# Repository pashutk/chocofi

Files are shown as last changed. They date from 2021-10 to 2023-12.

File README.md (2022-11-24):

# chocofi

Keyboard shield and 3d printed case to use with Arduino ProMicro-like contoller.

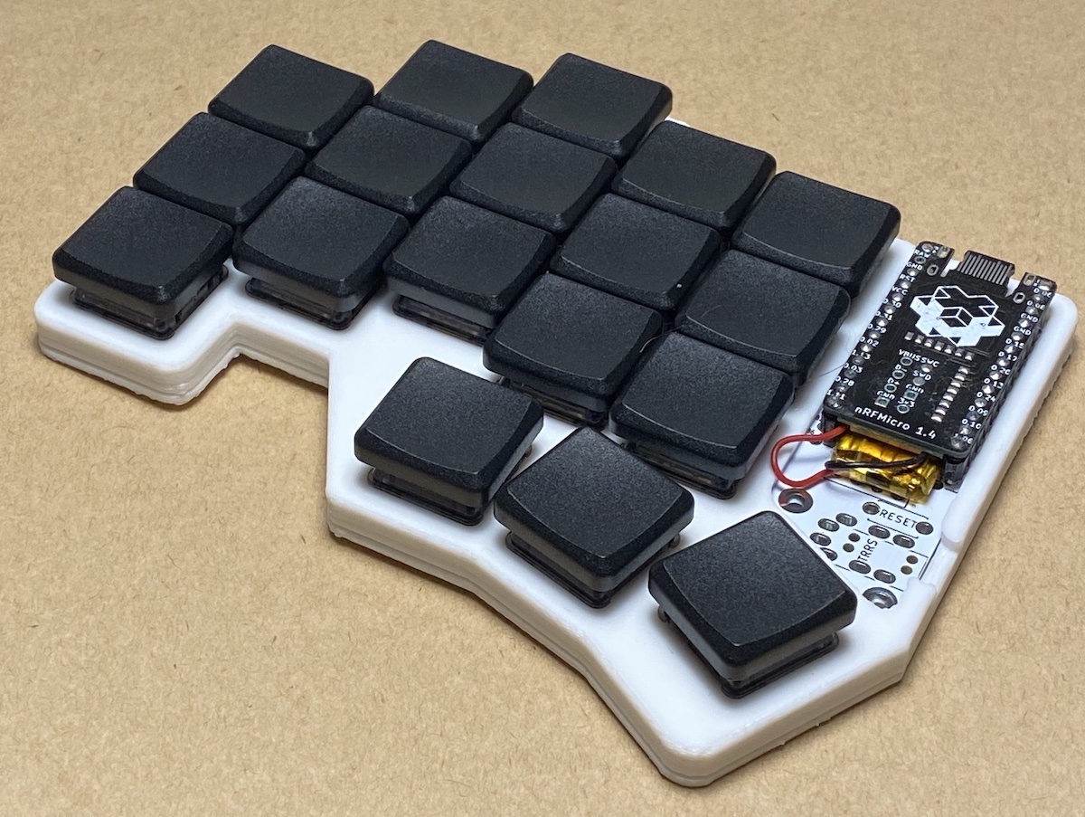
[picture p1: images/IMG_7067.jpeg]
Photo of a chocofi keyboard


- Split keyboard with 3 rows, 5 columns, and 3 thumbs per half
- Increased pinky column stagger
- Inspired by [Fifi keyboard](https://github.com/raychengy/fifi_split_keeb)
- Double-sided pcb (pcb can be used as left or right half)
- Pro Micro compatible footprint
- Easy to print, FDM-friendly two-piece case

## Artifacts

Gerbers are here: [pcb](/pcb/gerber.zip) and [top plate](/pcb/gerber-plate.zip)

Stls are here: [case folder](/case)

For more photos check out the [images folder](/images)

## By the way

Recommended batteries:

- [Nice nano docs](https://nicekeyboards.com/docs/nice-nano/#recommended-batteries-and-sockets) explains some basics
- [nRFmicro wiki](https://github.com/joric/nrfmicro/wiki/Batteries#301230) contains links to Aliexpress

Awesome libs used:

- [kbd.pretty](https://github.com/foostan/kbd) by foostan
- [keyswitches.pretty](https://github.com/daprice/keyswitches.pretty) by daprice

Also closest alternatives are:

- [raychengy/fifi](https://github.com/raychengy/fifi_split_keeb): non choc (mx switches)
- [davidphilipbarr/chocorne](https://github.com/davidphilipbarr/36keys/tree/master/42Keys/chocorne): non hotswap but choc-spaced corne (you can break off one column so it will be 5x3, but with corne pinky stagger)

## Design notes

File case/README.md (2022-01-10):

# Use v1 if you're not sure

v0 is case with switch cutouts 14.9x14.9mm size. It was exported like that to match tolerances on my printer. You probably want to use v1 which is 13.9x13.9mm cutouts (standard size).

More in the [issue #1](https://github.com/pashutk/chocofi/issues/1).

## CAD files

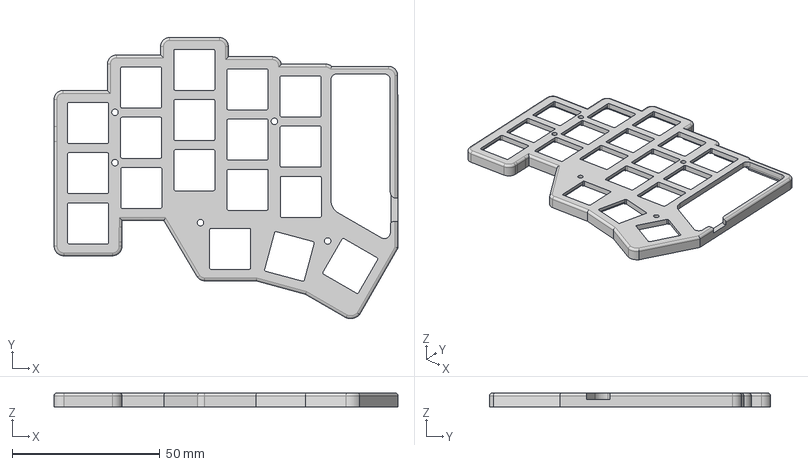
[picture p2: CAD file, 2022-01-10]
case/v1/top.step
116.5 x 95.2 x 4.80 mm

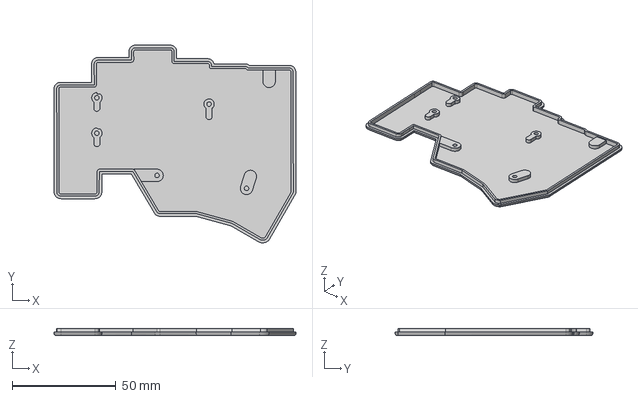
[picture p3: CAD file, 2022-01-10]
case/v1/bottom.step
116.5 x 95.2 x 3.40 mm

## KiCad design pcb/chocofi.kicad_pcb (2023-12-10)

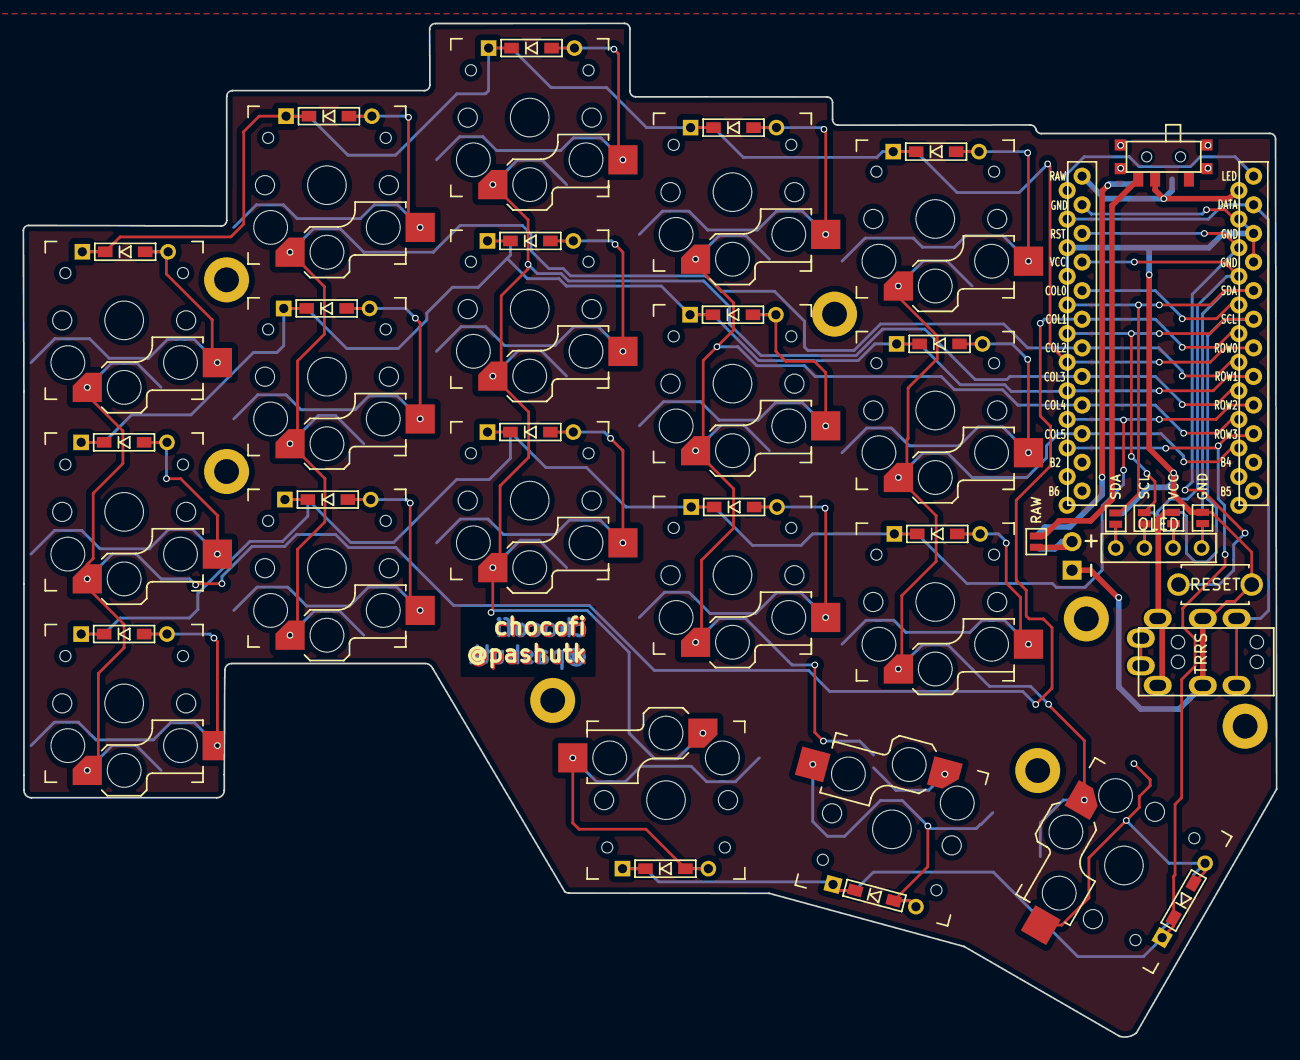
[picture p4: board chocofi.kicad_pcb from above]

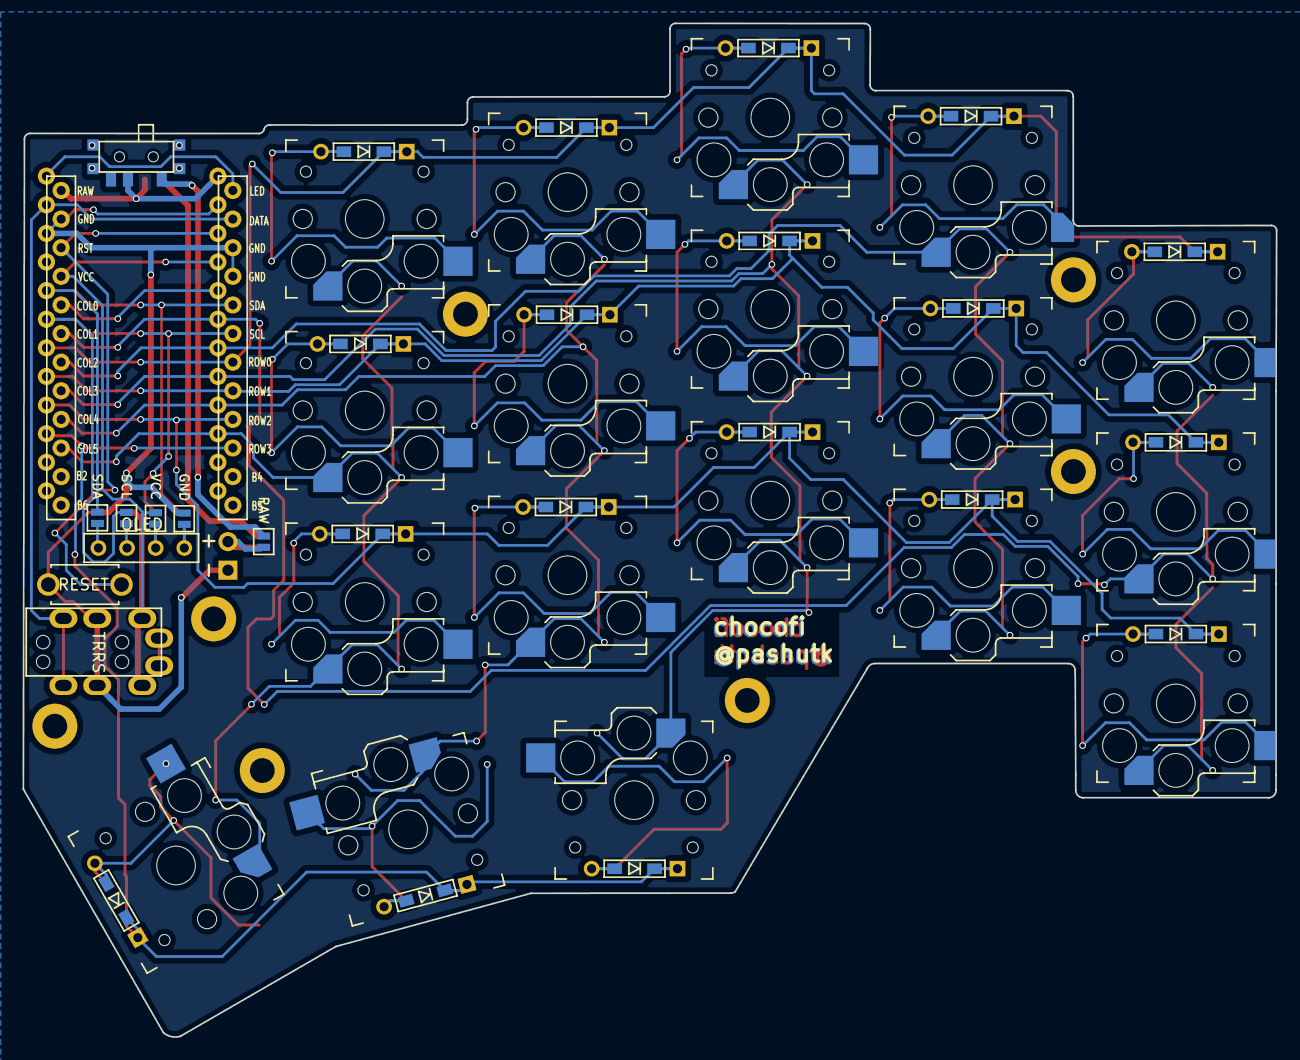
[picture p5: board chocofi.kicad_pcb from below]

Board: 2 copper layers, 111.3 x 90.0 mm, 60 parts (6 on the bottom side), 40 nets.

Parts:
D2, D3, D4, D5, D6, D8, D9, D10, D11, D12, D14, D15, D16, D17, D18, D19, D20, D21: D; D3_TH_SMD
H1: h1; LEGO_HOLE
J1: MJ-4PP-9
J2: OLED
J3: Conn_01x02_Female; Battery_TH
JP6, JP61: SDA; Jumper
JP61#2, JP62#2: RAW; Jumper
JP62, JP68: GND; Jumper
JP63, JP66: SCL; Jumper
JP64, JP65: VCC; Jumper
RSW1: Val**; ResetSW
SW1, SW2#2: SW_SPDT; SW_SPDT+H-MSK12C01_hor(7pin_SMD)
SW2, SW3, SW4, SW5, SW6, SW8, SW9, SW10, SW11, SW12, SW14, SW15, SW16, SW17, SW18, SW19, SW20, SW21: SW_PUSH; Kailh_socket_PG1350_reversible
U1: ProMicro; ProMicro_v2
h2: h2; LEGO_HOLE
h3: h3; LEGO_HOLE
h4: h4; LEGO_HOLE
h5: h5; LEGO_HOLE
h6: h6; LEGO_HOLE
h7: h7; LEGO_HOLE

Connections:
BAT_PLUS: J3.2, JP61#2.2, JP62#2.2
GND: J1.C, J3.1, JP62.1, JP68.1, RSW1.1, U1.3, U1.4, U1.23
unnamed: D2.2, SW2.2
unnamed: D3.2, SW3.2
unnamed: D4.2, SW4.2
unnamed: D5.2, SW5.2
unnamed: D6.2, SW6.2
unnamed: D8.2, SW8.2
unnamed: D9.2, SW9.2
unnamed: D10.2, SW10.2
unnamed: D11.2, SW11.2
unnamed: D12.2, SW12.2
unnamed: D14.2, SW14.2
unnamed: D15.2, SW15.2
unnamed: D16.2, SW16.2
unnamed: D17.2, SW17.2
unnamed: D18.2, SW18.2
unnamed: D19.2, SW19.2
unnamed: D20.2, SW20.2
unnamed: D21.2, SW21.2
unnamed: J2.3, JP65.2, JP66.2
unnamed: J2.4, JP6.2, JP68.2
unnamed: J2.2, JP63.2, JP64.2
unnamed: J2.1, JP61.2, JP62.2
unnamed: SW1.2 (B), SW2#2.2 (B), U1.24
SCL: JP63.1, JP66.1, U1.6
SDA: JP6.1, JP61.1, U1.5
SW_RAW_2: JP61#2.1, SW1.3 (C)
VCC: J1.D, JP64.1, JP65.1, U1.21
col1: SW2.1, SW8.1, SW14.1, U1.19
col2: SW3.1, SW9.1, SW15.1, U1.18
col3: SW4.1, SW10.1, SW16.1, SW19.1, U1.17
col4: SW5.1, SW11.1, SW17.1, SW20.1, U1.16
col5: SW6.1, SW12.1, SW18.1, SW21.1, U1.15
data: J1.B, U1.2
reset: RSW1.2, U1.22
row0: D2.1, D3.1, D4.1, D5.1, D6.1, U1.7
row1: D8.1, D9.1, D10.1, D11.1, D12.1, U1.8
row2: D14.1, D15.1, D16.1, D17.1, D18.1, U1.9
row3: D19.1, D20.1, D21.1, U1.10

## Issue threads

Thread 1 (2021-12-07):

top.stl switch plate holes too big

hmngwy, 2021-12-07:
Hello, I printed the case but found that the switch fit isn't snug, after some measuring I found that the holes are 15mm in width and height. 13.8mm w*h is the ideal hole size for choc switches, even the 14mm for MX switches are a bit loose. I would modify this and send a PR but I don't have the time right now to learn how to, so just letting you know for now. :(

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

Forgive the ruler work, the ruler tool in FreeCad doesn't snap to a grid.

pashutk, 2021-12-22:
@hmngwy Sorry for a late reply!

Initially I extruded 13.9x13.9 cuts but they was too tight to me. I guess that can be caused by bad z-offset on my printer, so I've exported version of the top with 13.9x13.9 cutouts, can you please test it?

There is an stl:
[Top2.stl.zip](https://github.com/pashutk/chocofi/files/7764676/Top2.stl.zip)

pashutk, 2022-01-10:
I've also added 13.9 version case stl files as v0 to [case](https://github.com/pashutk/chocofi/tree/main/case/) folder and moved prev version to v0.

AlexanderLindkjaer, 2022-01-22:
Hi @pashutk, printed the 13.9 version and they fit perfectly 🙂

pashutk, 2022-01-24:
@AlexanderLindkjaer Thank you for testing, that's great news!
Seems like this issue should be closed now.

Closed 2022-01-24.

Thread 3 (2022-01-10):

Please share step files for case top and bottom

pfn, 2022-01-10:
Hi @pashutk chocofi is great, and I'm currently using it now, I'm looking at encasing it, and want to make some mods to the case, like for a power switch, could you share the step files so that it would be easier to make modifications, please? Thank you!

pashutk, 2022-01-10:
Hi @pfn, glad you like it!

I've added step files in case folder, please check https://github.com/pashutk/chocofi/tree/main/case/v1. Please let me know if this won't work.

pfn, 2022-01-10:
This looks great, imports OK  and I should be able to use this to make my edits. Thank you!

Closed 2022-01-13.

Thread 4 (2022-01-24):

Screw size on case, possible issue with tolerance

AlexanderLindkjaer, 2022-01-24:
I @pashutk , love the keyboard nice work :)

What screw size is intended for the case? On most cases M2 is the standard. The screw holes are 2.4 mm, so way too big for M2 screws. So I'm thinking you are either using bigger screws or its a tolerance issues on your printer you had to adjust for. Like the plate holes V1 issue.

I modified the v1 case to fit m2 screws, on a printer with tight tolerance (1.9 mm screw holes). Let me know if you want a pull request.

pashutk, 2022-01-28:
@AlexanderLindkjaer oh huge thanks, it's definitely the same problem as in #1
But it also could be a M2.5. Let me check, I'm sure that holes should be for M2, and if that's the case I will update stls.
I think there is no need for PR since its easier to fix this issue in source file and then regenerate stls.
Thanks again.

AlexanderLindkjaer, 2022-01-28:
@pashutk Great! Let me know if you need me to test the case on my printer 🙂

If you or anybody reading wants to know the tolerance on their printer, a test like this can be printed
https://www.thingiverse.com/thing:2318105

pfn, 2022-02-09:
https://www.thingiverse.com/thing:5239708 -- I recently remixed the case to add tenting holes, and also had to fix the screw hole sizing: it has a 1.1mm radius, where it needs to be 1mm; M2 screws drop in. If your printer is that off (v0 case) your extrusion is probably too high and/or your x/y steps got badly misconfigured.

dcardamo, 2023-06-12:
I found a bottom case where the hole size was corrected to be m2 on thingiverse.   Sharing in case that helps anyone else:
https://www.thingiverse.com/thing:5239708

pfn, 2023-06-12:
See the comment immediately above yours  :D

azzamsa, 2023-06-12:
Anyone had the fixed screw location but without tenting feet holes?

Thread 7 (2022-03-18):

License

lilactown, 2022-03-18:
I'm interested in riffing on some of the designs (e.g. the case) in this repo. Is that something you would permit? If so, adding a license to the repo would be great.

pashutk, 2022-03-18:
@lilactown Sure, I'll add license file later and it probably will be MIT or CERN OHL. Both of them are pretty permissive license so you're totally free to work on your own case design.

pashutk, 2022-04-05:
Resolved by 7fce89f7734e740779f05d8ccd0215602c2ab4f6, thanks again

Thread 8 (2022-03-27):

Are the provided gerbers original, or production gerbers

Cgboal, 2022-03-27:
I sent off the gerbers for this board to JLBPCB yesterday, and they got back to me asking the following:

>Sorry to bother you, but there is an issue that we want to confirm with you before proceeding.
As shown below, It seems that the gerber file is working production file with compensation on the holes and trace for production.
If it is original file, we will make the compensation on the hole and trace. If it is production file, we will proceed without compensation.
For the file generated from the software, and has not been used for production, we call it original file.
So shall we proceed as per the gerber file with further compensation and optimization or not?

Are you able to shed some light on what the correct response is?

pashutk, 2022-03-27:
Hi @Cgboal!

Could you attach images they sent to you? Thanks

Cgboal, 2022-03-27:
Sure thing, thanks for the quick response
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

pashutk, 2022-03-27:
I wonder what compensations exactly they are talking about.

Anyway, this files were used to make a pcbs before, so I'd suggest you to proceed without any compensations. Please update the issue in case of any new information!

Cgboal, 2022-03-27:
Ok cool will do. Seems like from this doc on a different provider that different places handle compensation differently depending on their kit. https://www.pcbway.com/helpcenter/technical_support/Can_I_send_the_working_gerber_files_to_PCBWay_for_PCB_production_.html

Cgboal, 2022-03-28:
They also said that regarding the case designs, some places were very thin and risked cracking (red areas in pictures). Told them to go ahead with it anyway but I thought i'd post it here for posterity.
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

pashutk, 2022-03-28:
Thank you for posting! That's unlikely will cause any problems especially when printing fdm or sla (not sure how mjf will perform though).

Cgboal, 2022-03-28:
Guess we’ll find out :D

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

pashutk, 2022-04-05:
@Cgboal damn that was fast.

Could you please share a photo of the black pcb, especially the region where controller should be?
And what about cases? Did they turn out well?

Cgboal, 2022-04-05:
Hey, just started putting this together. I bought through hole diodes and soldered them on, but seems like the switches then don't fit with the diodes in place. I'm guessing I should be using SMD's instead? Good thing I have a few spare boards

pashutk, 2022-04-06:
SMD is probably will have better fit for this case, yes. I think regular 1n4148-like diodes should work too since they are not as tall as hotswap sockets?

Btw I'm looking at the photo and it seems that they've made thicker traces. Could you please ask them if they did compensation on holes for the green ones?

Cgboal, 2022-04-06:
As far as I know they did compensation on the green one, but no compensation on the black ones.

I've ordered some SMDs now which should work. Now I've got to find a battery that fits 🙄

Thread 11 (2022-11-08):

MX switches

the-argus, 2022-11-08:
The board in the images folder looks like it works both with mx and choco switches, though I can't quite tell. A friend of mine ordered the board for me, and is 3D printing the chassis, so I don't know much about the build. I just would like to know if mx switches will fit in the board. I know the fifi exists but its nice to have the option.

pashutk, 2022-11-18:
Hi @the-argus!
Unfortunately, MX switches wouldn't fit, it's a choc-only board. And it's basically Fifi board tuned for chocs specifically, so yeah, if you want MX you go with Fifi, and for chocs there's Chocofi.

the-argus, 2022-11-25:
thanks for the clarification!

Closed 2022-11-25.

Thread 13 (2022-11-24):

Recommended battery version

zaddok, 2022-11-24:
What battery numbers do people find works best to slide under the nano? I’ve seen one person use the 301230.   Perhaps the ideal options could be listed in the readme for reference?

zaddok, 2022-11-24:
The nice nano documentation itself recommends the 301230, so thats probably the way to go for anyone looking:

https://nicekeyboards.com/docs/nice-nano/

pashutk, 2022-11-24:
Hi @zaddok!

Well, Chocofi may be used as a wired split without any need for batteries, so it depends on the controller you use.

But the general recommendation would be yes, use 301230 lipos, nice nano docs is a great source, and also there is Joric's wiki https://github.com/joric/nrfmicro/wiki/Batteries#301230.

zaddok, 2022-11-24:
Thanks @pashutk — I'm very excited to try my board (I have ordered a set from beekeeb so it all comes from in the mail at the same time,  I am just checking out what battery to buy).

pashutk, 2022-11-24:
I've added links to README (https://github.com/pashutk/chocofi/commit/49de38354cee7bea771488ee05ffbd5a3cc248c1), thank you for raising the issue.

That's amazing, hope you'll like it! Please contact me if there are any problems.

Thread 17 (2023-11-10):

Add Leds?

TJohn0312, 2023-11-10:
Hello, I'm thinking about making a second set of this keyboard with leds, would I be able to solder in leds in the diode slot and be able to program them?

And If am able to put in leds, would I need to do anything special if I put the leds on top of the board, underneath the keys?

KastenTaco, 2024-04-28:
This version of the chocofi does not take LEDs. You can not replace diodes for LEDs

Closed 2024-06-05.

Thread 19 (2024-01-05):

Question about heat set insert for chocofi case

jittapont, 2024-01-05:
I want to know the dimensions of the heat set insert for the chocofi case (https://github.com/pashutk/chocofi/tree/main/case/v1)
Thanks

KastenTaco, 2024-04-28:
I am using M2 screws without inserts on mine. You will have to resize the holes to whatever inserts you plan to use.

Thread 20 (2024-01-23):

Question : Can the case be printed in metal?

nouritsu, 2024-01-23:
I want to build a keyboard that will last slightly higher temperatures, the place where I live comes slightly too close to the SLA max temperatures. Is the PCB good to go in a metal enclosure? If yes, are there any additional steps I have to take?

Zoltan-Balazs, 2024-09-22:
Did you manage to print it in metal?
I'm looking to do the same and wondering if anyone had success with it

leikoilja, 2025-02-05:
@nouritsu , may I ask, where do you live? 😅

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

nouritsu, 2025-02-07:
I was under the impression that SLA printed articles need to be stored in an environment with temperatures below 30-35C. I used to live in a small coastal town in India, where temperatures would often go up to 43C during the harsher times in summer. I was afraid the case would deform if the temperatures got too harsh.

I understand that this is not the case, though 😅

I ended up building the [Temper](https://github.com/raeedcho/temper) keyboard and went caseless.

leikoilja, 2025-02-07:
haha, great choice on a temper tho! i have just finish my first build on the temper as well, lovely build! but i went with 3d printed casing.
@nouritsu , do you have pics of how your caseless looks? Did you plasticglass for the plates?

nouritsu, 2025-02-21:
Unfortunately I do not have the keyboard with me at the moment. However, here https://photos.app.goo.gl/T8FoAUFAczT2QjPv8 is an old photo.

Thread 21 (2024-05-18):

Screw size

rickdgray, 2024-05-18:
Doesn't seem to be any documentation on the size of screw needed for the case. I have M2s and M3s but neither fit, so I'm guessing M2.5? Roughly 6mm long?

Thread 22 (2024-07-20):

Hardware components for Chocfi

goldic342, 2024-07-20:
I'm gonna built chocofi keyboard, but I can't found any list of components for keyboard like diodes or power switch.
Is there any list? If not can you tell me what components should I use.

light-tech, 2025-01-11:
For now, you could open the schematic and export the Bill of Materials from there

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

Here is the CSV I got:

```csv
"Reference","Value","Datasheet","Footprint","Qty","DNP"
"D1,D2,D3,D4,D5,D6,D7,D8,D9,D10,D11,D12,D13,D14,D15,D16,D17,D18,D19,D20,D21,D22,D23,D24,D25,D26,D27,D28,D29,D30,D31,D32,D33,D34,D35,D36,D37,D38,D39,D40,D41,D42","D","","kbd:D3_TH","42",""
"J1,J6","MJ-4PP-9","","kbd:MJ-4PP-9_1side","2",""
"J2,J7","OLED","","kbd:OLED_1side","2",""
"RSW1,RSW2,SW1,SW2,SW3,SW4,SW5,SW6,SW7,SW8,SW9,SW10,SW11,SW12,SW13,SW14,SW15,SW16,SW17,SW18,SW19,SW20,SW21,SW22,SW23,SW24,SW25,SW26,SW27,SW28,SW29,SW30,SW31,SW32,SW33,SW34,SW35,SW36,SW37,SW38,SW39,SW40,SW41,SW42","SW_PUSH","","-- mixed values --","44",""
"U1,U2","ProMicro","","kbd:ProMicro_v2_1side","2",""
```

The board are using 42 through hole diodes (you are free to choose but 4148 is typically used in this field). You can choose a different SMD diode if desired but that requires changing the schematic, update the PCB, and the PCB traces.

goldic342, 2025-01-12:
Thank you!

Closed 2025-01-12.

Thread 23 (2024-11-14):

Missing trace on the right side PCB (power switch-> RAW jumper).

articnet, 2024-11-14:
As per picture, if this trace is not connected, the right side does not currently switch on (can be solved by attaching the switch on the bottom and connecting the bottom jumper or by connecting a wire as in the picture). Am I missing something?

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

TannerGabriel, 2025-03-31:
Yes, I just had the same issue.  I could fix the board layout, but it looks like the schematic and board are out of sync. It seems like #9 only modified the board and didn't add the power switch to the schematic.

TannerGabriel, 2025-04-05:
@pashutk If possible, could you confirm that the schematic wasn't updated and if so do you still have the updated schematic file?

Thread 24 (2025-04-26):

Unclear Jumper Soldering

Marlon154, 2025-04-26:
I'm trying to build the keyboard but I can't find any instructions about which side of the PCB to solder the jumpers on. The documentation doesn't specify whether these should be soldered on the top or bottom side of the PCB. In the Fifi doc the OLED is on the top side what is about the extra jumper (left most one in the image)?

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

Currently I have both soldered on the top side but I it not working.
There might be another issue...

Closed 2025-05-10.

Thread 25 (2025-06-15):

Add holes for reset button/on-off switch

skorokithakis, 2025-06-15:
Would it be possible to add holes for the reset button and the on/off switch? This case is great, but without a hole for the button and switch, it won't fit a wireless keyboard.

anjandev, 2025-06-20:
Hey, if youve 3d printed the case with pla, you can just use an exacto knife to make room for the button.

skorokithakis, 2025-06-20:
I did, but that never looks as good as printing it like that to begin with... It would be good if we could get the sources to mod them.

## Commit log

2021-08-29 Fix refs
    [chocofi-B_Cu.gbr, chocofi-B_Mask.gbr, chocofi-B_Paste.gbr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]
2021-08-29 add top plate
    [chocofi-topplate-B_Cu.gbr, chocofi-topplate-B_Mask.gbr, chocofi-topplate-B_Paste.gbr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]
2021-10-10 Remove excessive corner pad surface, rm doorka logo
    [chocofi-topplate.kicad_pcb, chocofi.kicad_pcb, chocofi1.dsn]
2021-10-10 Mv everything to pcb folder
    [chocofi-B_Cu.gbr, chocofi-B_Mask.gbr, chocofi-B_Paste.gbr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]
2021-10-10 Regenerate gerber files
    [chocofi-B_Cu.gbl, chocofi-B_Mask.gbs, chocofi-B_Paste.gbp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]
2021-10-10 Compress new gerbers
2021-10-10 Add case
2022-01-10 Add 13.9x13.9mm switch cutouts top case, add step files
    [bottom.step, top.step]
2022-01-18 Pcb: add corne-light-rescue
2022-01-23 Add power switch. Broken nets on scheme.
    [chocofi-B_Cu.gbl, chocofi-B_Mask.gbs, chocofi-B_Paste.gbp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]
2022-09-29 Use thicker power trace
    [chocofi.kicad_pcb]
